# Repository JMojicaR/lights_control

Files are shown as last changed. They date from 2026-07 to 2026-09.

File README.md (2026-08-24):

# Staircase Light Controller — ESP32-S3

Automatically controls a 12V LED strip on a 5m staircase using **VL53L0X ToF presence detection**, ambient light, and time-of-day logic. Includes a **web dashboard** for live monitoring and manual override.

## How It Works

```
Person on stairs?  ──┐
It's dark?          ──┤──▶ All 3 true? ──▶ LIGHTS ON
Past sunset?        ──┘

Any condition false ────────────────▶ LIGHTS OFF (after timeout)
```

**Decision logic:**
1. **VL53L0X ToF** (bottom of stairs) measures distance via laser — detects presence within a configurable range (3–15cm, default 7cm)
2. **VL53L0X ToF** (top of stairs) — same, for the upper landing (independent threshold)
3. **BH1750** measures ambient light (lux) — ensures lights don't fire during daytime
4. **sunrise-sunset.org API** provides sunset time for your location — lights only at night
5. Lights stay ON for a configurable duration (default 90s) after turning on, then turn OFF — the presence interrupt is disarmed while the lights are on, so continued presence on the stairs can't reset the countdown
6. **Manual override** via web dashboard — force ON / OFF / AUTO

Presence is detected by **hardware interrupt, not polling**. Each VL53L0X's
GPIO1 pin is configured as an active-low threshold interrupt that fires the
moment the measured distance drops below the per-sensor threshold. The ESP32
attaches an interrupt handler that registers presence and turns the lights on.

The interrupt is **armed only after sunset and while the lights are OFF** — it is
disarmed while the lights are on (so the countdown runs to completion) and
re-armed when they go off. Ghost/crosstalk readings below 3cm are still filtered
out, and the presence threshold is configurable **3cm to 15cm** (default 7cm).
The ambient-light BH1750 sensor is still polled (**5s by default**, configurable),
since lux changes slowly.

### Why VL53L0X instead of PIR?

| Feature | HC-SR501 PIR | VL53L0X ToF |
|---|---|---|
| Detection method | Passive infrared (heat movement) | Laser time-of-flight (distance) |
| Still person | ❌ Not detected | ✅ Detected |
| Hot environments | ❌ Fails (ambient ≈ body temp) | ✅ Works |
| Output | Binary (HIGH/LOW) | Distance in mm |
| Range | ~5m cone | Up to 2m (reliable ~1.2m) |
| Interface | Single digital pin | I²C (shared bus) + GPIO1 interrupt output |
| Multi-sensor | 1 pin each | XSHUT pin + unique I²C address |

## Web Dashboard

Open `http://<esp32-ip>/` in any browser on the same network.

| Tile | Description |
|---|---|
| **Live status** | Lights ON/OFF, ambient lux, distance (cm) bottom/top, local time, sunset |
| **Manual override** | Force ON, Force OFF, or return to AUTO mode |
| **Uptime & RSSI** | Device uptime and WiFi signal strength |
| **Duration / Distance / Poll** | Set light duration (s), per-sensor presence distance (mm), and ambient-light (BH1750) polling interval (s), persisted to NVS |
| **JSON API** | `GET /api` returns machine-readable JSON |
| **Override API** | `GET /api/override?mode=on\|off\|auto` for programmatic control |
| **Distance API** | `POST /api/distance?position=bottom\|top&mm=N` to set a presence threshold |
| **Poll API** | `POST /api/poll?seconds=N` to set the ambient-light polling interval |
| **Auto-refresh** | Dashboard polls every 2 seconds |

### API Examples

```bash
# Get current status
curl http://192.168.1.42/api
# → {"lights_on":false,"duty":0,"lux":3.5,"presence_bottom":true,"presence_top":false,
#    "distance_bottom_mm":450,"distance_top_mm":2100,"time":"14:30","sunset":"19:15",...}

# Force lights on (e.g., from a script or home automation)
curl "http://192.168.1.42/api/override?mode=on"
# → {"override":"on","lights_on":true}

# Return to automatic mode
curl "http://192.168.1.42/api/override?mode=auto"
# → {"override":"auto","lights_on":false}

# Set light duration (seconds)
curl -X POST "http://192.168.1.42/api/duration?seconds=120"
# → {"duration_sec":120,"active_duration_sec":120,"persisted":true,"ok":true}

# Set presence distance thresholds (mm, 30–150)
curl -X POST "http://192.168.1.42/api/distance?position=bottom&mm=60"
# → {"position":"bottom","distance_mm":60,"ok":true}
curl -X POST "http://192.168.1.42/api/distance?position=top&mm=50"
# → {"position":"top","distance_mm":50,"ok":true}

# Set sensor polling interval (seconds, 1–300)
curl -X POST "http://192.168.1.42/api/poll?seconds=10"
# → {"poll_interval_sec":10,"ok":true}
```

## Hardware

| Component | Purpose | GPIO / I²C |
|---|---|---|
| ESP32-S3 SuperMini | Controller | — |
| VL53L0X ToF (bottom) | Presence detection (bottom of stairs) | I²C addr 0x29, XSHUT GPIO 4, IRQ GPIO 7 |
| VL53L0X ToF (top) | Presence detection (top of stairs) | I²C addr 0x30, XSHUT GPIO 6, IRQ GPIO 8 |
| BH1750 | Ambient light sensor | I²C 0x23 (SDA 12, SCL 13) |
| IRLZ44N MOSFET | Switch 12V LED strip | 5 (PWM-capable) |
| 12V LED strip (5m) | Staircase lighting | MOSFET drain |
| 12V DC PSU (≥6A) | Power for LED strip | — |

### Wiring

```
ESP32-S3              Peripheral
────────              ──────────
GPIO 4   ──────────── VL53L0X #1 XSHUT (bottom)
GPIO 6   ──────────── VL53L0X #2 XSHUT (top)
GPIO 7   ──────────── VL53L0X #1 GPIO1 (bottom, interrupt out)
GPIO 8   ──────────── VL53L0X #2 GPIO1 (top, interrupt out)
GPIO 12  ──────────── VL53L0X #1 SDA, VL53L0X #2 SDA, BH1750 SDA
GPIO 13  ──────────── VL53L0X #1 SCL, VL53L0X #2 SCL, BH1750 SCL
3.3V    ──────────── VL53L0X VIN (×2), BH1750 VCC
GND     ──────────── VL53L0X GND (×2), BH1750 GND

VL53L0X XSHUT pins must have 10KΩ pull-up to 3.3V (many modules include this).
GPIO1 is the sensor's active-low interrupt output — wire it to the ESP32 IRQ pin
listed above (a 10KΩ pull-up to 3.3V is harmless, and required if your module's
GPIO1 is open-drain).
All three I²C devices share the same SDA/SCL bus — unique addresses assigned at boot.

MOSFET circuit:
GPIO 5 ──[10KΩ]──┬── IRLZ44N GATE
                 └── GND

12V PSU (+) ─── LED strip (+) ─── LED strip (-) ─── IRLZ44N DRAIN
12V PSU (-) ─── IRLZ44N SOURCE ─── GND (common)
```

## APIs Used

| API | Endpoint | Purpose | Key Required? |
|-----|---|---|---|
| timeapi.io | `timeapi.io/api/v1/time/current/zone?timezone={tz}` | Current time + timezone | No |
| sunrise-sunset.org | `api.sunrise-sunset.org/json` | Sunset/sunrise times | No |

Both are free, no API key needed.

## Configuration

Edit `config.h` before flashing:

```cpp
#define WIFI_SSID       "YOUR_SSID"
#define WIFI_PASSWORD   "YOUR_PASSWORD"
#define LATITUDE        19.4326    // Your location
#define LONGITUDE       -99.1332
#define TIMEZONE        "America/Mexico_City"
#define LUX_THRESHOLD   30         // Lux below this = "dark"
#define VL53L0X_MIN_PRESENCE_MM 30   // 3cm — minimum sensing range (ghost-reading floor)
#define DISTANCE_DEFAULT_MM  70      // 7cm — default presence distance (configurable via dashboard)
#define DEFAULT_LIGHT_DURATION_SEC  90  // Seconds to keep lights on after detection
#define VL53L0X_IRQ_BOTTOM  7        // Bottom sensor GPIO1 (interrupt out) → ESP32 GPIO 7
#define VL53L0X_IRQ_TOP     8        // Top sensor GPIO1 (interrupt out)    → ESP32 GPIO 8
#define POLL_INTERVAL_DEFAULT_SEC 5  // Ambient-light (BH1750) polling interval (configurable via dashboard)
```

The presence distance (bottom and top, independently), light duration, and
ambient-light polling interval can all be changed live from the dashboard — values
are persisted to NVS and survive reboot. Allowed presence distance range: **30–150 mm**
(3–15cm). Lux polling interval range: **1–300 s** (default 5s).

## Build & Flash

```bash
# Install dependencies (first time only)
arduino-cli lib install BH1750
arduino-cli lib install ArduinoJson
arduino-cli lib install VL53L0X

# Compile
arduino-cli compile --fqbn esp32:esp32:esp32s3 .

# Flash
arduino-cli upload -p /dev/ttyUSB0 --fqbn esp32:esp32:esp32s3 .

# Monitor
arduino-cli monitor -p /dev/ttyUSB0 -c baudrate=115200
```

## Serial Output

```
=== Staircase Light Controller ===
[✓] VL53L0X bottom ready (addr 0x29)
[✓] VL53L0X top ready (addr 0x30)
[🔔] Bottom sensor → interrupt on GPIO 7 (threshold 70mm)
[🔔] Top sensor → interrupt on GPIO 8 (threshold 70mm)
[✓] BH1750 ready
[✓] WiFi connected — IP: 192.168.1.42
[⏰] Time synced: 2026-07-10T16:19:26-06:00 (UTC-6, DST=no)
[🌅] Sunset: 2026-06-27T01:15:00 UTC  |  Sunrise: 2026-06-26T12:00:00 UTC
[🌐] Dashboard: http://192.168.1.42/
--- Ready ---
[STATUS] 14:30:15 | Lux: 450 | Bottom: clear (2100mm) | Top: clear (2050mm) | Lights: OFF | Sunset: 19:15 | Mode: AUTO
[🔔] Presence interrupts armed
[👣] Presence detected — bottom! (450 mm)
[💡] Decision: ON  (presence=1 dark=1 night=1 lux=3)
[💡] Lights → ON (fading in)
[🔕] Presence interrupts disarmed
```

## Dependencies (Arduino Libraries)

| Library | Version | Install |
|---|---|---|
| VL53L0X | ≥1.3.0 | `arduino-cli lib install VL53L0X` |
| BH1750 | ≥1.3.0 | `arduino-cli lib install BH1750` |
| ArduinoJson | ≥7.0 | `arduino-cli lib install ArduinoJson` |

WiFi, HTTPClient, Wire, and **WebServer** are included with the ESP32 board package.

## Enclosure Models

FreeCAD (.FCStd) and STL models for 3D printing are in `enclosures/`:

| File | Description |
|---|---|
| `enclosures/main_box.fcstd` | Main controller enclosure (ESP32-S3 + MOSFET + terminals) |
| `enclosures/sensor_bottom.fcstd` | VL53L0X housing — bottom of stairs |
| `enclosures/sensor_top.fcstd` | VL53L0X housing — top of stairs |
| `enclosures/bh1750_housing.fcstd` | BH1750 ambient light sensor housing |

Print in PETG or ABS for heat resistance (PLA may warp near the MOSFET).

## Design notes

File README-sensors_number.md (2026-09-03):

# Plan — Configurable VL53L0X sensor count (branch `sensors_number`)

## Goal

Let the system be configured to run with **1 or 2** VL53L0X ToF sensors via the
web dashboard, and have that choice applied **before** the sensors are
configured and read at boot.

## Approach

The sensor count is a boot-time setting persisted to NVS. It is read in
`setup()` *before* the VL53L0X init block, so only the configured number of
sensors is initialized. The dashboard exposes a dropdown (1 or 2) that writes
the value to NVS through a new API endpoint; the change takes effect on the next
reboot.

Why "reboot to apply" rather than hot reconfiguration: the two sensors share one
I²C bus and must be assigned unique addresses (0x29 / 0x30) in a specific
order. Re-assigning those addresses safely while a sensor is already running is
fragile, so the count is resolved once at boot.

## Changes made

### `config.h`
- Added `SENSOR_COUNT_DEFAULT` (2), `SENSOR_COUNT_MIN` (1), `SENSOR_COUNT_MAX` (2).

### `lights_control.ino`
1. Added NVS key `PREF_KEY_SENSOR_COUNT` and global `configuredSensorCount`.
2. `setup()` now loads the persisted count (clamped to 1–2) in the same block
   that loads duration / distance / poll settings — i.e. **before** sensor init.
3. Sensor init block:
   - Top sensor is only initialized when `configuredSensorCount >= 2`; with 1
     sensor its XSHUT pin stays LOW (shutdown) so it can never collide on the bus.
   - Bottom sensor is always initialized (count >= 1).
   - Reachability check now guarded by `tofXReady` (skips reads on missing sensors).
4. New endpoint `GET|POST /api/sensors?count=1|2` (clamped, persisted to NVS,
   returns `reboot_required:true`).
5. `/api` JSON now includes `sensor_count`.
6. Dashboard: added a "Sensors" dropdown (1 / 2) with a Set button that calls
   the new endpoint.

## Verification

- Compiles clean for `esp32:esp32:esp32s3` (86% flash, 14% RAM — unchanged budget).
- With `count=1` the top sensor stays in shutdown; bottom initializes at 0x29.
- With `count=2` the existing top-first / bottom-second address assignment is
  preserved (no address collision).

## Potential blockers / risks

1. **Runtime hot-swap is out of scope.** Changing the count requires a reboot.
   Re-assigning I²C addresses at runtime is possible but fragile; if live
   reconfiguration is ever required it should be its own change (see the
   `sensors_scan` branch for hot-plug recovery of a *missing* sensor, which is a
   different concern).
2. **Setting `count=2` with only one sensor wired** — the missing sensor's
   `init()` fails gracefully (logged as "not found") and the system runs with
   one sensor. No crash, but no automatic retry either (again, that is the
   `sensors_scan` branch's job).
3. **NVS key is new** — first boot after flashing uses the default (2 sensors),
   so existing single-sensor units must be configured once via the dashboard.
4. **Flash budget** — the sketch is already at 86% of program storage; large
   additions (e.g. a full config UI) could push it over the 1310720-byte limit.
5. **Wiring assumption** — "1 sensor" is interpreted as *bottom only* (the
   sensor on the default 0x29 address / bottom XSHUT GPIO 4). If a single
   physical sensor is wired to the *top* position instead, it would not be
   detected. The physical-to-logical mapping should be documented per install.

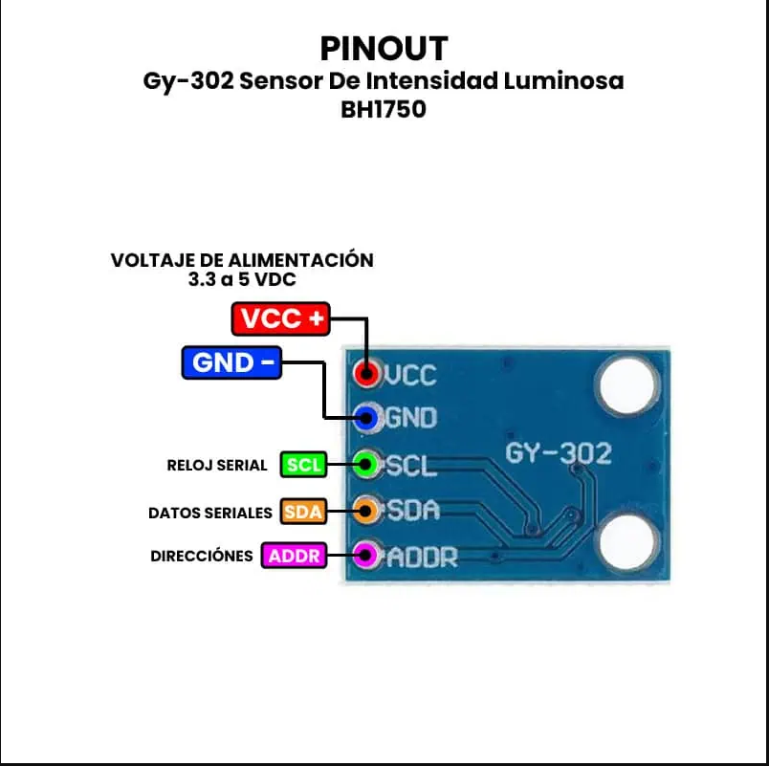
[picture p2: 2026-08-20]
pinout_datasheets/BH1750_pinout.png

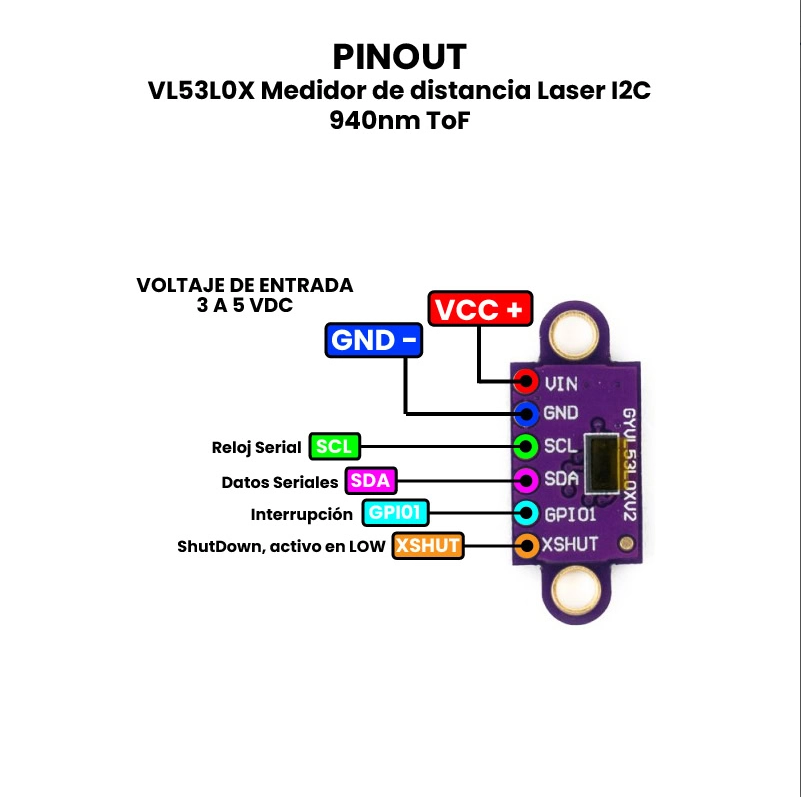
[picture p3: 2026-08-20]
pinout_datasheets/VL53L0.png

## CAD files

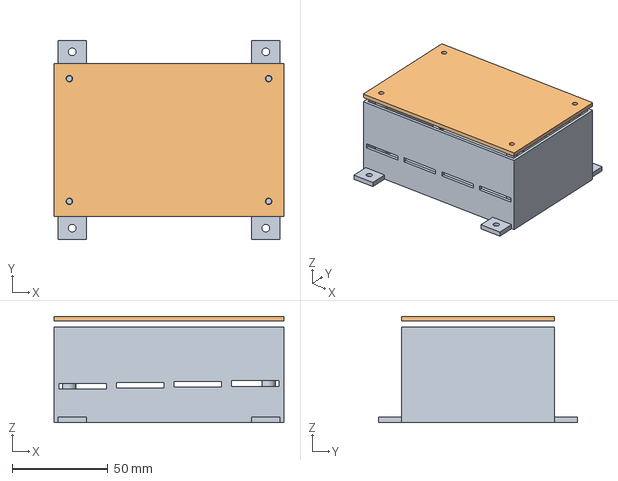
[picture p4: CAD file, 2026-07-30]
enclosures/main_box.FCStd
120.0 x 104.0 x 55.5 mm
EnclosureBody
Lid

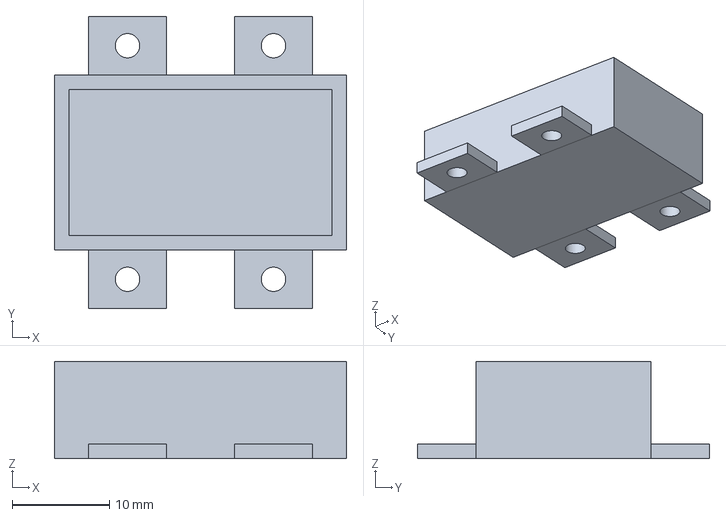
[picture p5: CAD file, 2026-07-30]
enclosures/sensor_top.FCStd
30.0 x 30.0 x 10.0 mm

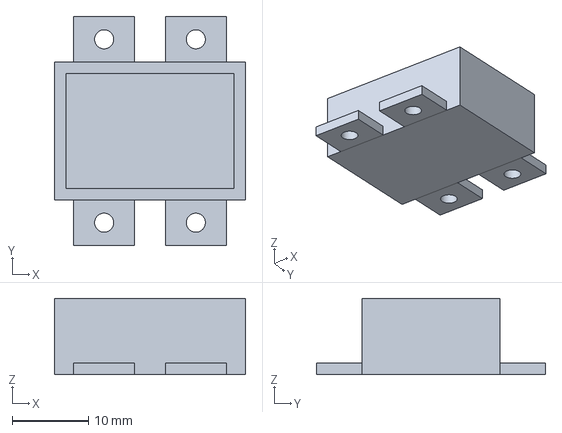
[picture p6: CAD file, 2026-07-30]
enclosures/bh1750_housing.FCStd
25.0 x 30.0 x 10.0 mm

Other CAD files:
enclosures/sensor_bottom.FCStd

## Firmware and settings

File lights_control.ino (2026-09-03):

/**
 * Staircase Light Controller — ESP32-S3 SuperMini
 * ===============================================
 *
 * Automatically controls a 12V LED strip on a 5m staircase based on:
 *   1. Presence detection (VL53L0X ToF laser distance sensors)
 *   2. Ambient light level (BH1750 I²C lux sensor)
 *   3. Time of day vs sunset (HTTP APIs)
 *
 * Lights turn ON when: person detected on stairs AND it's dark AND past sunset.
 * Presence is detected via VL53L0X hardware interrupts (GPIO1 threshold output),
 * not polling. Interrupts are armed only after sunset and while the lights are
 * OFF; they are disarmed while the lights are ON and re-armed when they go off,
 * so the countdown is never reset by continued presence on the stairs.
 *
 * VL53L0X advantages over HC-SR501 PIR:
 *   - Detects presence even when person is still (no movement needed)
 *   - Works in hot environments (PIR fails when ambient ≈ body temp)
 *   - Provides actual distance in mm for richer dashboard data
 *
 * Web Dashboard: http://<esp32-ip>/
 *   - Live status: lux, distance (cm), lights, time, sunset
 *   - Manual override: force ON / OFF / AUTO
 *
 * APIs used:
 *   - timeapi.io          (https://timeapi.io)        — current time
 *   - sunrise-sunset.org                              — sunset/sunrise times
 *
 * Hardware:
 *   - ESP32-S3 SuperMini
 *   - VL53L0X ToF distance sensor — bottom of stairs (I²C addr 0x29, XSHUT GPIO 4, IRQ GPIO 7)
 *   - VL53L0X ToF distance sensor — top of stairs (I²C addr 0x30, XSHUT GPIO 6, IRQ GPIO 8)
 *   - BH1750 ambient light sensor (I²C: SDA 12, SCL 13)
 *   - IRLZ44N MOSFET switching 12V LED strip (GPIO 5)
 *   - 12V DC power supply (≥6A for 5m strip)
 */

#include "config.h"
#include <WiFi.h>
#include <HTTPClient.h>
#include <Wire.h>
#include <BH1750.h>
#include <VL53L0X.h>
#include <ArduinoJson.h>
#include <WebServer.h>
#include <time.h>
#include <Preferences.h>

// ── Objects ─────────────────────────────────────
BH1750 lightMeter;
VL53L0X tofBottom;   // Bottom of stairs (I²C addr 0x29)
VL53L0X tofTop;      // Top of stairs (I²C addr 0x30)
WebServer server(80);
Preferences prefs;

const char* PREF_NAMESPACE = "stairs";
const char* PREF_KEY_DURATION = "dur_sec";
const char* PREF_KEY_DIST_BOTTOM = "dist_bottom_mm";
const char* PREF_KEY_DIST_TOP = "dist_top_mm";
const char* PREF_KEY_POLL = "poll_sec";
const char* PREF_KEY_SENSOR_COUNT = "sensor_count";

// ── Time tracking ───────────────────────────────
unsigned long lastTimeSync   = 0;      // millis() of last HTTP time sync
unsigned long lastSunsetSync = 0;      // millis() of last sunset sync
time_t        currentEpoch   = 0;      // current Unix time (from HTTP)
time_t        sunsetEpoch    = 0;      // today's sunset Unix time
time_t        sunriseEpoch   = 0;      // today's sunrise Unix time
bool          timeValid      = false;
bool          sunsetValid    = false;
int           localUtcOffsetSec = -6 * 3600; // Updated from time API (Mexico City offset)
const unsigned long TIME_RESYNC_MS   = TIME_RESYNC_MIN  * 60000UL;
const unsigned long SUNSET_RESYNC_MS = SUNSET_RESYNC_MIN * 60000UL;

// ── Presence tracking (VL53L0X) ──────────────────
bool     presenceBottom  = false;
bool     presenceTop     = false;
uint16_t distanceBottom  = 0;        // mm
uint16_t distanceTop     = 0;        // mm
bool     tofBottomReady  = false;    // Bottom sensor initialized
bool     tofTopReady     = false;    // Top sensor initialized

// ── Interrupt-driven presence (VL53L0X GPIO1) ────
volatile bool irqBottomTriggered = false;  // Set by bottom-sensor ISR
volatile bool irqTopTriggered    = false;  // Set by top-sensor ISR
bool     interruptsArmed  = false;   // True while presence interrupts are attached
unsigned long lastMotionTime = 0;
unsigned long motionDebounceUntil = 0;

// ── Light state ─────────────────────────────────
bool     lightsOn        = false;
unsigned long lightsOnSince  = 0;

// ── PWM Fade ────────────────────────────────────
int      currentDuty     = 0;     // Current PWM duty cycle (0-255)
int      targetDuty      = 0;     // Desired PWM duty cycle
unsigned long fadeStartMs = 0;    // When the current fade began

// ── Dynamic light duration (changeable via HTTP) ─
unsigned long configuredDurationSec = DEFAULT_LIGHT_DURATION_SEC; // Used for new sessions
unsigned long activeDurationSec     = DEFAULT_LIGHT_DURATION_SEC; // Locked for current session

// ── Dynamic presence distance thresholds (changeable via HTTP) ─
unsigned long configuredDistanceBottomMm = DISTANCE_DEFAULT_MM;  // bottom sensor presence threshold
unsigned long configuredDistanceTopMm    = DISTANCE_DEFAULT_MM;  // top sensor presence threshold

// ── Dynamic sensor polling interval (changeable via HTTP) ─
unsigned long configuredPollIntervalSec = POLL_INTERVAL_DEFAULT_SEC;  // seconds between sensor reads

// ── Number of VL53L0X sensors (changeable via HTTP, persisted to NVS) ─
// Read in setup() BEFORE sensor init so the correct number initializes.
unsigned long configuredSensorCount = SENSOR_COUNT_DEFAULT;

// ── Manual override ─────────────────────────────
//  0 = AUTO (use sensor/sunset logic)
//  1 = FORCE ON
// -1 = FORCE OFF
int      overrideMode    = 0;

// ── Sensor readings ─────────────────────────────
float    lux             = 0.0;

// ── Uptime tracking ─────────────────────────────
unsigned long bootMillis = 0;

// ─────────────────────────────────────────────────
// SETUP
// ─────────────────────────────────────────────────
void setup() {
    Serial.begin(115200);
    delay(250);
    Serial.println("\n=== Staircase Light Controller ===\n");

    // Load persisted settings (fallback to compile-time defaults).
    if (prefs.begin(PREF_NAMESPACE, true)) {
      unsigned long savedDur = prefs.getULong(PREF_KEY_DURATION, DEFAULT_LIGHT_DURATION_SEC);
      unsigned long savedBottom = prefs.getULong(PREF_KEY_DIST_BOTTOM, DISTANCE_DEFAULT_MM);
      unsigned long savedTop = prefs.getULong(PREF_KEY_DIST_TOP, DISTANCE_DEFAULT_MM);
      unsigned long savedPoll = prefs.getULong(PREF_KEY_POLL, POLL_INTERVAL_DEFAULT_SEC);
      unsigned long savedCount = prefs.getULong(PREF_KEY_SENSOR_COUNT, SENSOR_COUNT_DEFAULT);
      prefs.end();

      if (savedDur >= DURATION_MIN_SEC && savedDur <= DURATION_MAX_SEC) {
        configuredDurationSec = savedDur;
      } else {
        configuredDurationSec = DEFAULT_LIGHT_DURATION_SEC;
        Serial.printf("[⚠] Stored duration invalid (%lu) — using default %lu\n",
                savedDur, configuredDurationSec);
      }

      configuredDistanceBottomMm = (savedBottom >= DISTANCE_MIN_MM && savedBottom <= DISTANCE_MAX_MM)
                                   ? savedBottom : DISTANCE_DEFAULT_MM;
      configuredDistanceTopMm    = (savedTop >= DISTANCE_MIN_MM && savedTop <= DISTANCE_MAX_MM)
                                   ? savedTop : DISTANCE_DEFAULT_MM;
      configuredPollIntervalSec  = (savedPoll >= POLL_INTERVAL_MIN_SEC && savedPoll <= POLL_INTERVAL_MAX_SEC)
                                   ? savedPoll : POLL_INTERVAL_DEFAULT_SEC;
      configuredSensorCount      = (savedCount >= SENSOR_COUNT_MIN && savedCount <= SENSOR_COUNT_MAX)
                                   ? savedCount : SENSOR_COUNT_DEFAULT;
    } else {
      configuredDurationSec = DEFAULT_LIGHT_DURATION_SEC;
      Serial.printf("[⚠] Preferences unavailable — using default duration %lu\n",
              configuredDurationSec);
    }
    activeDurationSec = configuredDurationSec;
    Serial.printf("[⚙] Loaded: duration %lus | dist bottom %lumm | dist top %lumm | poll %lus | sensors %lu\n",
                  configuredDurationSec, configuredDistanceBottomMm,
                  configuredDistanceTopMm, configuredPollIntervalSec, configuredSensorCount);

    // Pins — LED MOSFET uses PWM for fade
    pinMode(STATUS_LED_PIN, OUTPUT);
    digitalWrite(STATUS_LED_PIN, LOW);

    // I²C for BH1750 + VL53L0X (shared bus)
    Wire.begin(I2C_SDA, I2C_SCL);

    // ── VL53L0X ToF sensor init (two sensors on same I²C bus) ──
    // Strategy: hold both in shutdown, then wake one at a time. The FIRST
    // sensor woken MUST be moved off the default 0x29 address before the
    // second wakes — otherwise both boot at 0x29 and a setAddress() write
    // hits both (address collision → constant 65535 readings).
    pinMode(VL53L0X_XSHUT_BOTTOM, OUTPUT);
    pinMode(VL53L0X_XSHUT_TOP, OUTPUT);
    digitalWrite(VL53L0X_XSHUT_BOTTOM, LOW);  // Hold both in shutdown
    digitalWrite(VL53L0X_XSHUT_TOP, LOW);
    delay(10);

    // Init TOP first: wake it at 0x29, then move it to the alternate address
    // (0x30) so the default 0x29 is free for the bottom sensor. The top sensor
    // is only initialized when the configured sensor count is 2; with 1 sensor
    // its XSHUT stays LOW (shutdown) so it can never collide on the bus.
    if (configuredSensorCount >= 2) {
        digitalWrite(VL53L0X_XSHUT_TOP, HIGH);
        delay(10);
        if (tofTop.init(true)) {  // true = use 2.8V mode (more stable)
            tofTop.setAddress(VL53L0X_ADDR_ALT);
            tofTop.setTimeout(500);
            tofTop.setMeasurementTimingBudget(VL53L0X_TIMING_BUDGET_MS * 1000UL);
            Serial.printf("[✓] VL53L0X top ready (addr 0x%02X)\n", tofTop.getAddress());
            tofTopReady = true;
        } else {
            Serial.println("[✗] VL53L0X top not found — check wiring");
        }
    } else {
        Serial.printf("[ℹ] Sensor count = %lu — top sensor disabled (XSHUT held LOW)\n",
                      configuredSensorCount);
    }

    // Init BOTTOM second: it boots at the default 0x29, now free.
    digitalWrite(VL53L0X_XSHUT_BOTTOM, HIGH);
    delay(10);
    if (tofBottom.init(true)) {
        tofBottom.setAddress(VL53L0X_ADDR_DEFAULT);
        tofBottom.setTimeout(500);
        tofBottom.setMeasurementTimingBudget(VL53L0X_TIMING_BUDGET_MS * 1000UL);
        Serial.printf("[✓] VL53L0X bottom ready (addr 0x%02X)\n", tofBottom.getAddress());
        tofBottomReady = true;
    } else {
        Serial.println("[✗] VL53L0X bottom not found — check wiring");
    }

    // ── Post-init reachability check ──
    // Verify each sensor actually answers at its assigned address. This catches
    // an address collision (a sensor silently moved to the wrong address would
    // otherwise read as a constant 65535).
    if (tofBottomReady && tofBottom.readReg(VL53L0X::IDENTIFICATION_MODEL_ID) != 0xEE) {
        Serial.println("[⚠] Bottom sensor not reachable at 0x29 — possible address collision");
    }
    if (tofTopReady && tofTop.readReg(VL53L0X::IDENTIFICATION_MODEL_ID) != 0xEE) {
        Serial.println("[⚠] Top sensor not reachable at 0x30 — possible address collision");
    }

    // ── Configure VL53L0X GPIO1 as a presence interrupt ──
    // Each sensor's GPIO1 pin is set to fire (active LOW) whenever the measured
    // distance drops below the presence threshold, then continuous ranging is
    // started. Detection is now interrupt-driven — no polling loop.
    if (tofBottomReady) {
        configureToFInterrupt(tofBottom, configuredDistanceBottomMm);
        tofBottom.startContinuous(VL53L0X_INTERMEASUREMENT_MS);
        pinMode(VL53L0X_IRQ_BOTTOM, INPUT_PULLUP);
        Serial.printf("[🔔] Bottom sensor → interrupt on GPIO %d (threshold %lumm)\n",
                      VL53L0X_IRQ_BOTTOM, configuredDistanceBottomMm);
    }
    if (tofTopReady) {
        configureToFInterrupt(tofTop, configuredDistanceTopMm);
        tofTop.startContinuous(VL53L0X_INTERMEASUREMENT_MS);
        pinMode(VL53L0X_IRQ_TOP, INPUT_PULLUP);
        Serial.printf("[🔔] Top sensor → interrupt on GPIO %d (threshold %lumm)\n",
                      VL53L0X_IRQ_TOP, configuredDistanceTopMm);
    }

    // BH1750 lux sensor init
    if (!lightMeter.begin(LIGHT_SENSOR_MODE, 0x23, &Wire)) {
        Serial.println("[✗] BH1750 not found — check wiring");
    } else {
        Serial.println("[✓] BH1750 ready");
    }

    // PWM setup for LED MOSFET (8-bit, 5 kHz — silent, smooth fade)
    ledcAttach(LED_MOSFET_PIN, PWM_FREQ, PWM_RES);
    ledcWrite(LED_MOSFET_PIN, 0);

    // WiFi
    connectWiFi();

    // Initial time sync
    syncTime();
    syncSunset();

    // ── Web server routes ─────────────────────────
    server.on("/", handleRoot);
    server.on("/api", handleAPI);
    server.on("/api/override", handleOverride);
    server.on("/api/duration", handleDuration);
    server.on("/api/distance", handleDistance);
    server.on("/api/poll", handlePoll);
    server.on("/api/sensors", handleSensorCount);
    server.onNotFound([]() {
        server.send(404, "application/json", "{\"error\":\"not found\"}");
    });
    server.begin();
    bootMillis = millis();
    Serial.printf("[🌐] Dashboard: http://%s/\n", WiFi.localIP().toString().c_str());

    Serial.println("\n--- Ready ---\n");
}

// ─────────────────────────────────────────────────
// LOOP
// ─────────────────────────────────────────────────
void loop() {
    server.handleClient();  // non-blocking — serves web requests (runs every loop)

    unsigned long now = millis();

    // ── Periodic HTTP time re-sync ───────────────
    if (now - lastTimeSync >= TIME_RESYNC_MS || !timeValid) {
        syncTime();
    }

    // ── Periodic sunset re-sync ──────────────────
    if (now - lastSunsetSync >= SUNSET_RESYNC_MS || !sunsetValid) {
        syncSunset();
    }

    // ── ToF presence (interrupt-driven) + presence timeout ──
    // VL53L0X presence is handled by hardware interrupts, not polling. The ISRs
    // latch flags that are consumed here; the presence timeout (turn the lights
    // off after the configured duration) also runs every loop.
    processTofInterrupts();

    // ── Ambient light (BH1750) polling (configurable interval, default 5s) ──
    // The ToF sensors no longer need polling; only the lux sensor is read on a
    // cadence, keeping the web server fully responsive.
    static unsigned long lastLuxPoll = 0;
    unsigned long luxPollMs = configuredPollIntervalSec * 1000UL;
    if (lastLuxPoll == 0 || now - lastLuxPoll >= luxPollMs) {
        lastLuxPoll = now;
        readLux();
    }

    // ── Decision logic + light control (every loop — keeps override responsive) ──
    setLights(evaluate());

    // ── Arm/disarm presence interrupts based on time + light state ──
    updateInterrupts();

    // ── PWM fade tick (fixed cadence → smooth fade regardless of polling) ──
    static unsigned long lastFadeTick = 0;
    if (now - lastFadeTick >= FADE_TICK_MS) {
        lastFadeTick = now;
        updateFade();
    }

    // ── Status LED heartbeat ─────────────────────
    digitalWrite(STATUS_LED_PIN, lightsOn ? HIGH : (now / 1000) % 2);

    // ── Serial report every 5 seconds ────────────
    static unsigned long lastReport = 0;
    if (now - lastReport >= 5000) {
        lastReport = now;
        printStatus();
    }

    delay(LOOP_DELAY_MS);
}

// ═════════════════════════════════════════════════
// WiFi
// ═════════════════════════════════════════════════
void connectWiFi() {
    Serial.printf("WiFi: connecting to %s", WIFI_SSID);
    WiFi.begin(WIFI_SSID, WIFI_PASSWORD);
    int attempts = 0;
    while (WiFi.status() != WL_CONNECTED && attempts < 40) {
        delay(500);
        Serial.print(".");
        attempts++;
    }
    if (WiFi.status() == WL_CONNECTED) {
        Serial.printf("\n[✓] WiFi connected — IP: %s\n", WiFi.localIP().toString().c_str());
    } else {
        Serial.println("\n[✗] WiFi failed — will retry");
    }
}

// ═════════════════════════════════════════════════
// Time Helpers (UTC-safe)
// ═════════════════════════════════════════════════

long daysFromCivil(int y, unsigned m, unsigned d) {
  y -= m <= 2;
  const int era = (y >= 0 ? y : y - 399) / 400;
  const unsigned yoe = (unsigned)(y - era * 400);
  const unsigned doy = (153 * (m + (m > 2 ? -3 : 9)) + 2) / 5 + d - 1;
  const unsigned doe = yoe * 365 + yoe / 4 - yoe / 100 + doy;
  return era * 146097L + (long)doe - 719468L;
}

time_t buildUtcEpoch(int year, int month, int day, int hour, int minute, int second) {
  long days = daysFromCivil(year, (unsigned)month, (unsigned)day);
  long long secs = (long long)days * 86400LL +
           (long long)hour * 3600LL +
           (long long)minute * 60LL +
           (long long)second;
  return (time_t)secs;
}

int parseIsoOffsetSeconds(const String& iso) {
  int n = iso.length();
  if (n >= 1 && iso.charAt(n - 1) == 'Z') {
    return 0;
  }
  if (n >= 6 && (iso.charAt(n - 6) == '+' || iso.charAt(n - 6) == '-') && iso.charAt(n - 3) == ':') {
    int sign = (iso.charAt(n - 6) == '-') ? -1 : 1;
    int offH = atoi(iso.substring(n - 5, n - 3).c_str());
    int offM = atoi(iso.substring(n - 2, n).c_str());
    return sign * ((offH * 3600) + (offM * 60));
  }
  return 0;
}

time_t isoToEpoch(const char* iso) {
  String s = String(iso);
  if (s.length() < 19) return 0;

  int year   = atoi(s.substring(0, 4).c_str());
  int month  = atoi(s.substring(5, 7).c_str());
  int day    = atoi(s.substring(8, 10).c_str());
  int hour   = atoi(s.substring(11, 13).c_str());
  int minute = atoi(s.substring(14, 16).c_str());
  int second = atoi(s.substring(17, 19).c_str());
  int offsetSec = parseIsoOffsetSeconds(s);

  // ISO timestamp encodes local wall time + offset. Convert to UTC epoch.
  time_t wallEpoch = buildUtcEpoch(year, month, day, hour, minute, second);
  return wallEpoch - offsetSec;
}

void formatHHMMFromEpoch(time_t epochUtc, int utcOffsetSec, char* out, size_t outSize) {
  time_t localEpoch = epochUtc + utcOffsetSec;
  struct tm tmUtc = {};
  gmtime_r(&localEpoch, &tmUtc);
  strftime(out, outSize, "%H:%M", &tmUtc);
}

void formatHHMMSSFromEpoch(time_t epochUtc, int utcOffsetSec, char* out, size_t outSize) {
  time_t localEpoch = epochUtc + utcOffsetSec;
  struct tm tmUtc = {};
  gmtime_r(&localEpoch, &tmUtc);
  strftime(out, outSize, "%H:%M:%S", &tmUtc);
}

// Local minutes-since-midnight for a UTC epoch (0..1439).
// Time-of-day comparisons are immune to the calendar-date offset between UTC
// and local time (a western timezone's sunset lands on the *next* UTC date).
int minutesOfDay(time_t epochUtc, int utcOffsetSec) {
  time_t localEpoch = epochUtc + utcOffsetSec;
  struct tm tmUtc = {};
  gmtime_r(&localEpoch, &tmUtc);
  return tmUtc.tm_hour * 60 + tmUtc.tm_min;
}

// Local calendar date (YYYY-MM-DD) for a UTC epoch — used to request today's
// sunrise/sunset from the API instead of letting it default to the UTC date.
void formatLocalDate(time_t epochUtc, int utcOffsetSec, char* out, size_t outSize) {
  time_t localEpoch = epochUtc + utcOffsetSec;
  struct tm tmUtc = {};
  gmtime_r(&localEpoch, &tmUtc);
  strftime(out, outSize, "%Y-%m-%d", &tmUtc);
}

// ═════════════════════════════════════════════════
// HTTP: Sync current time from timeapi.io
// ═════════════════════════════════════════════════
void syncTime() {
    if (WiFi.status() != WL_CONNECTED) {
        connectWiFi();
        if (WiFi.status() != WL_CONNECTED) return;
    }

    HTTPClient http;
    String url = String(TIME_API_URL) + TIMEZONE;
    http.begin(url);
    http.setTimeout(8000);

    int code = http.GET();
    if (code == 200) {
        String payload = http.getString();
        StaticJsonDocument<1024> doc;
        DeserializationError err = deserializeJson(doc, payload);

        if (!err) {
            const char* dt = doc["date_time"];       // "2026-07-10T16:19:26.627199-06:00"
            int utcOffset = doc["utc_offset_seconds"];// seconds offset from UTC
          bool dstActive = doc["dst_active"];

          time_t parsedEpoch = isoToEpoch(dt);
          if (parsedEpoch == 0) {
            Serial.println("[✗] Time parse error");
            http.end();
            return;
          }

          currentEpoch = parsedEpoch;
          localUtcOffsetSec = utcOffset;
            timeValid = true;
            lastTimeSync = millis();

          char localNow[16];
          formatHHMMSSFromEpoch(currentEpoch, localUtcOffsetSec, localNow, sizeof(localNow));
          Serial.printf("[⏰] Time synced: %s | Local: %s | UTC offset: %+d h (DST=%s)\n",
                  dt, localNow, utcOffset / 3600, dstActive ? "yes" : "no");
        } else {
            Serial.printf("[✗] Time JSON parse error: %s\n", err.c_str());
        }
    } else {
        Serial.printf("[✗] Time HTTP %d\n", code);
    }
    http.end();
}
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

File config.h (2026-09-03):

#ifndef CONFIG_H
#define CONFIG_H

// ── WiFi ────────────────────────────────────────
#define WIFI_SSID       "SSID"
#define WIFI_PASSWORD   "PASSWORD"

// ── Location & Timezone ─────────────────────────
// Used for the sunset API (sunrise-sunset.org)
#define LATITUDE        19.4326    // Mexico City (change to your location)
#define LONGITUDE       -99.1332
#define TIMEZONE        "America/Mexico_City"

// ── HTTP API Endpoints ──────────────────────────
// timeapi.io — returns current time in JSON (free, no API key)
#define TIME_API_URL    "https://timeapi.io/api/v1/time/current/zone?timezone="
// sunrise-sunset.org — returns sunrise/sunset times (free, no API key)
#define SUNSET_API_URL  "https://api.sunrise-sunset.org/json"

// ── Pins ────────────────────────────────────────
#define VL53L0X_XSHUT_BOTTOM  4   // VL53L0X ToF sensor at bottom of stairs (XSHUT pin)
#define VL53L0X_XSHUT_TOP     6   // VL53L0X ToF sensor at top of stairs (XSHUT pin)
#define VL53L0X_IRQ_BOTTOM    7   // VL53L0X bottom GPIO1 (interrupt out) → ESP32 GPIO 7
#define VL53L0X_IRQ_TOP       8   // VL53L0X top GPIO1 (interrupt out)    → ESP32 GPIO 8
#define LED_MOSFET_PIN        5   // IRLZ44N gate for 12V LED strip
#define STATUS_LED_PIN        2   // Built-in LED (2 = most ESP32-S3 SuperMini)

// BH1750 + VL53L0X share I²C (default pins on ESP32-S3 SuperMini)
#define I2C_SDA         12
#define I2C_SCL         13

// ── Light & Motion Thresholds ───────────────────
#define LUX_THRESHOLD       30    // Lux below this = "dark enough" for lights
#define DEFAULT_LIGHT_DURATION_SEC  90  // Keep lights ON this many seconds after last motion (default, changeable via HTTP)
#define MOTION_DEBOUNCE_MS          2000  // Ignore motion re-triggers within this window

// ── VL53L0X ToF Sensor Settings ──────────────────
// VL53L0X I²C addresses (when using two sensors on same bus)
#define VL53L0X_ADDR_DEFAULT  0x29  // Default I²C address (sensor 0 — bottom)
#define VL53L0X_ADDR_ALT      0x30  // Alternate address for second sensor (top)
// Number of VL53L0X sensors wired (1 = bottom only, 2 = bottom + top).
// Configurable at runtime via the dashboard, persisted to NVS, and read in
// setup() BEFORE the sensors are configured so the correct number initializes.
#define SENSOR_COUNT_DEFAULT  2     // Default number of sensors (2 = both)
#define SENSOR_COUNT_MIN      1     // Minimum — bottom sensor only
#define SENSOR_COUNT_MAX      2     // Maximum — bottom + top
// Presence detection window (mm): distance >= MIN and distance < threshold → person detected
// Measure range: 3cm floor, threshold configurable up to 15cm
#define VL53L0X_MIN_PRESENCE_MM  30    // 3cm — readings below this are ignored (ghost/crosstalk)
#define DISTANCE_DEFAULT_MM      70    // Default presence distance threshold (7cm), configurable via HTTP
#define DISTANCE_MIN_MM          30    // Shortest allowed presence distance (3cm)
#define DISTANCE_MAX_MM          150   // Longest allowed presence distance (15cm)
// Range status: 0=valid, other=out-of-range or error
#define VL53L0X_TIMING_BUDGET_MS  33  // 33ms = standard speed (~1.2m range)
#define VL53L0X_INTERMEASUREMENT_MS  50  // Continuous-ranging period (ms) between measurements

// ── Timing ──────────────────────────────────────
#define POLL_INTERVAL_DEFAULT_SEC  5    // Default sensor polling interval (seconds), configurable via HTTP
#define POLL_INTERVAL_MIN_SEC      1    // Shortest allowed polling interval
#define POLL_INTERVAL_MAX_SEC      300  // Longest allowed polling interval (5 min)
#define FADE_TICK_MS            250   // PWM fade step interval (keeps fade smooth regardless of polling)
#define LOOP_DELAY_MS           10    // Base loop delay — keeps web server + heartbeat responsive
#define TIME_RESYNC_MIN     60    // Re-sync time from HTTP every N minutes
#define SUNSET_RESYNC_MIN   360   // Re-sync sunset from HTTP every 6 hours

// ── PWM Fade ─────────────────────────────────────
#define PWM_CHANNEL         0     // LEDC channel for MOSFET PWM
#define PWM_FREQ            5000  // PWM frequency (Hz) — above audible range
#define PWM_RES             8     // 8-bit resolution = 0-255
#define FADE_STEP           8     // Duty change per tick (250ms tick → ~8 sec full range)
#define FADE_ON_MS          500   // Fade-in duration target (ms)
#define FADE_OFF_MS         1500  // Fade-out duration target (ms)

// ── Duration limits (for HTTP endpoint) ──────────
#define DURATION_MIN_SEC    5     // Shortest allowed light duration
#define DURATION_MAX_SEC    1800  // Longest allowed light duration (30 min)

// ── Sensor Calibration ──────────────────────────
// BH1750 modes (from BH1750::Mode enum):
//   BH1750::CONTINUOUS_HIGH_RES_MODE  — 1 lux resolution, 120ms
//   BH1750::CONTINUOUS_HIGH_RES_MODE2 — 0.5 lux resolution, 120ms
//   BH1750::CONTINUOUS_LOW_RES_MODE   — 4 lux resolution, 16ms
#define LIGHT_SENSOR_MODE  BH1750::CONTINUOUS_HIGH_RES_MODE

#endif

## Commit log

2026-06-29 feat: initial commit — staircase light controller
    ESP32-S3 SuperMini with HC-SR501 PIR motion sensor, BH1750 ambient
    light sensor, and IRLZ44N MOSFET controlling 12V LED strip.
    - Motion + darkness + past-sunset logic
    - HTTP time sync via WorldTimeAPI
    - HTTP sunset sync via sunrise-sunset.org (free, no API key)
    - 2-minute light timeout after last motion
    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
2026-07-10 feat: add web dashboard with manual override
    - Built-in WebServer on port 80 (no extra libraries)
    - Dark-themed responsive dashboard at http://<ip>/
    - Live status: lights, lux, motion, time, sunset, uptime, RSSI
    - Manual override: Force ON / OFF / AUTO via buttons or API
    - JSON API: GET /api and GET /api/override?mode=on|off|auto
2026-07-10 refactor: migrate time API from WorldTimeAPI to timeapi.io
    - New endpoint: https://timeapi.io/api/v1/time/current/zone?timezone=
    - Updated syncTime() to parse date_time, utc_offset_seconds, dst_active fields
    - Serial log now shows UTC offset and DST status instead of abbreviation
2026-07-18 feat: add PWM fade, configurable duration, and remaining time indicator
    - Replace digitalWrite with LEDC PWM for smooth fade in/out on lights
    - Add /api/duration HTTP endpoint (GET/POST) to set light-on duration
    - Add remaining-time tile to web dashboard with urgency coloring
    - Duration configurable via dashboard input (5s–30min range)
    - Serial status now shows remaining time and current duration
    [config.h, lights_control.ino]
2026-07-20 feat: add second PIR sensor at top of stairs
    - Add PIR_PIN_TOP (GPIO 6) alongside existing PIR_PIN_BOTTOM (GPIO 4)
    - Dual PIR tracking: motion from either sensor triggers lights
    - Independent motion state per PIR (bottom / top)
    - Motion timeout clears both states together
    - Web dashboard shows both PIR states with separate tiles
    - JSON API returns motion_bottom and motion_top fields
    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
2026-07-21 add correct pin mapping for BH1750
    [config.h, lights_control.ino]
2026-07-21 Add logic for set up time without revert to default each 2sec and persistence of time configuration
    [lights_control.ino]
2026-07-30 feat: replace HC-SR501 PIR with VL53L0X ToF sensors
    - Replace dual HC-SR501 PIR motion sensors with VL53L0X time-of-flight
    laser distance sensors for presence detection
    - Two VL53L0X on shared I²C bus (addr 0x29 bottom, 0x30 top)
    - XSHUT pins on GPIO 4 (bottom) and GPIO 6 (top) for multi-sensor init
    - Presence detected when distance < VL53L0X_PRESENCE_MM (default 1.2m)
    - VL53L0X advantages: detects still persons, works in hot environments,
    provides actual distance in mm for richer dashboard data
    - Dashboard: replaced Motion tiles with Distance (cm) + PRESENT/clear status
    - API: renamed motion_bottom/top → presence_bottom/top,
    added distance_bottom_mm/top_mm fields
    - Added 4 FreeCAD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
    [bh1750_housing.FCStd, main_box.FCStd, sensor_bottom.FCStd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]
2026-08-13 Add configurable presence distance, 15cm floor, duration+5s polling
    - Fix remaining-time stall: ignore VL53L0X ghost readings below 15cm and
    clamp remaining-time calc (was unsigned underflowing once elapsed > duration)
    - Poll ToF/BH1750 sensors every (duration + 5)s while keeping the web server,
    fade, and heartbeat responsive via a millis()-based loop
    - Make presence distance configurable per sensor (bottom/top) through
    /api/distance and the dashboard, persisted to NVS
    [config.h, lights_control.ino]
2026-08-13 Measure range 3-7cm, configurable 5s polling, fix dashboard input reset
    - Narrow presence measure range to 3cm-7cm (floor 30mm, threshold 70mm);
    distance inputs and /api/distance bounds updated accordingly
    - Replace duration+5s polling with a fixed configurable interval
    (default 5s, range 1-300s) via /api/poll + dashboard, persisted to NVS
    - Fix dashboard inputs resetting while typing: use document.activeElement
    guards instead of focus/blur editing flags
    [config.h, lights_control.ino]
2026-08-13 Allow presence threshold configurable up to 15cm (floor stays 3cm)
2026-08-13 Fix VL53L0X I2C address collision between bottom and top sensors
    The bottom sensor was woken first but left on the default 0x29 address, so
    when the top sensor woke it also booted at 0x29; the subsequent
    setAddress(0x30) write hit both sensors, stranding the bottom object at a
    dead 0x29 (constant 65535 readings).
    Reorder init to wake the top first and move it to 0x30, then wake the
    bottom at the now-free 0x29. Add a post-init model-ID reachability check
    per sensor to self-diagnose any future collision.
    [lights_control.ino]
2026-08-24 feat: switch VL53L0X presence detection from polling to interrupts
    Replace the 5s polling loop with hardware interrupts: each VL53L0X's GPIO1
    pin is configured as an active-low threshold interrupt that fires the moment
    the measured distance drops below the presence threshold, then continuous
    ranging runs in the background.
    Interrupt gating:
    - Armed only after sunset (nighttime) and while the lights are OFF in AUTO mode.
    - Disarmed while the lights are ON so continued presence can't reset the
    countdown, then re-armed when the lights go off.
    - Presence threshold changes via the dashboard update the hardware threshold.
    The BH1750 ambient-light sensor is still polled (lux changes slowly). Ad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
    [config.h, lights_control.ino]
2026-08-25 Fix night detection turning lights on before sunset
    sunrise-sunset.org defaults to the UTC date, so in the local evening
    (UTC-6) it returns tomorrow's sunrise/sunset. The absolute-epoch night
    check (now >= sunsetEpoch || now < sunriseEpoch) then classified the
    pre-sunset daytime as night, switching the lights on early.
    - Pass the local date explicitly (&date=YYYY-MM-DD) to the sunset API
    - Compare local times-of-day (minutesOfDay) instead of absolute epochs
    - Deduplicate: evaluate() now reuses isNightNow()
    [lights_control.ino]
2026-08-25 Fix presence immediately timing out (unsigned underflow)
    processTofInterrupts() captured now=millis() at function entry, then
    handleTofInterrupt() updated lastMotionTime to a later millis() value.
    The timeout check (now - lastMotionTime > duration) underflowed to a huge
    unsigned number, clearing presence the instant it was detected — so the
    lights never turned on. Use a fresh millis() in the timeout check.
    [lights_control.ino]
2026-09-03 feat: configurable VL53L0X sensor count (1 or 2) via dashboard
    Add a dashboard 'Sensors' control and /api/sensors endpoint that persists
    the sensor count (1 = bottom only, 2 = bottom + top) to NVS. The count is
    read in setup() BEFORE the sensor init block, so only the configured number
    of sensors is initialized. Includes plan/blocker doc.
